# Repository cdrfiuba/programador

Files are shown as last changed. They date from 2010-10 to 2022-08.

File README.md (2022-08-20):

# Programador del Club de Robótica

El club cuenta con varios programadores ISP.

Cada programador cuenta con dos conexiones:
* Target (targ)
    - La conexión más usada. Sirve para programar un microcontrolador externo.
* ISP
    - Sirve para programar el programador (usualmente usando otro programador del club).
      De esta forma un programador sirve para crear más programadores.

## Conexiones

Cada puerto cuenta con 6 pines conectados a un cable plano:

- VCC (usualmente +5V que vienen de la conexión USB)
- GND
- SCK Señal de clock.
- RESET Permite "apagar" el microcontrolador y programarlo por SPI. De esa forma los demás pines pueden ser usados para otras tareas cuando el microcontrolador no está siendo programado.
- MISO (master-in slave-out)<sup>1</sup> Datos del microcontrolador al programador.
- MOSI (master-out slave-in)<sup>1</sup> Datos del programador al microcontrolador.

<sup>1 Nota: SIMO y SOMI suelen ser nombres más simpáticos pero menos usados.</sup>

La ubicación de cada pin en el puerto se muestra a continuación

<p align="center">
    Ubicación de cada pin en el puerto.
</p>

## Pequeña guía para programar un microcontrolador externo

Se utiliza el microcontrolador `ATMEGA168A` a modo de ejemplo (ya que el club cuenta con varios).

La siguiente guía asume el uso de un oscilador externo, si bien el microcontrolador puede ser programador utilizando su oscilador interno.

Se conecta al microcontrolador como muestra la siguiente figura. El valor ideal de los capacitores conectados al cristal se detalla en la hoja de datos del microcontrolador. Para este microcontrolador los capacitores recomendados son de 12pF a 22pF. El capacitor de desacople no es requerido pero es siempre una buena idea agregar uno.

<p align="center">
    Diagrama de la conexión en un protoboard
</p>

Asumiendo que se utiliza un cristal de 16 MHz se crea un archivo `main.c` con el siguiente código:

```C
#include <avr/io.h>
#define F_CPU 16000000UL  // Corresponde a 16 MHz
#include <util/delay.h>

int main (void) {
  DDRC |= _BV(DDC3);  // Se setea el pin 26 como salida

  while(1) {
      PORTC |= _BV(PC3);  // Se prende el pin 26

      _delay_ms(1); // Se espera un milisegundo

      PORTC &= ~_BV(PC3);  // Se apaga el pin 26

      _delay_ms(1);  // Se espera otro milisegundo
  }

  return 1;
}
```

Este código produce una onda cuadrada de 500Hz a la salida del pin 26.

Para programadorlo se crea el siguiente script `programar.sh`

```bash
#!/usr/bin/env sh

# Compilación del programa
avr-gcc -Os -mmcu=atmega168a -c -o main.o main.c
avr-gcc -Os -mmcu=atmega168a -o main.elf main.o
avr-objcopy -O ihex -R .eeprom main.elf main.hex

# Cargar el programa en el microcontrolador
avrdude -v -p m168 -c usbtiny -U flash:w:main.hex

# Limpieza de los archivos generados
rm main.o main.hex main.elf
```

A su vez se crea un script `fusibles.sh` para setear los fuses del microcontrolador
Si bien se puede obtener el valor de los fusibles a mano, existen páginas que ya hacen este trabajo.
Una posible página es https://www.engbedded.com/fusecalc
Esta página además posee la ventaja de darnos los flags para el comando de `avrdude`.

```bash
#!/usr/bin/env bash

avrdude -v -p m168 -c usbtiny -U lfuse:w:0xce:m -U hfuse:w:0xdf:m -U efuse:w:0xf9:m
```

Se da permiso de ejecución a ambos scripts por única vez
```console
$ chmod +x programar.sh
$ chmod +x fusibles.sh
```

Se setean los fusibles por única vez. Puede correrse también en el futuro si, por ejemplo, se desea dividir la cuenta del clock por 8, o utilizar el oscilador interno u otras razones. Pero ha de tenerse en cuenta que se debe modificar el script.

```console
$ ./fusibles.sh
```

Se programa el microcontrolador

```console
$ ./programar.sh
```

Ahora puede corroborarse que a la salida del pin 26 hay una onda cuadrada de 500Hz.

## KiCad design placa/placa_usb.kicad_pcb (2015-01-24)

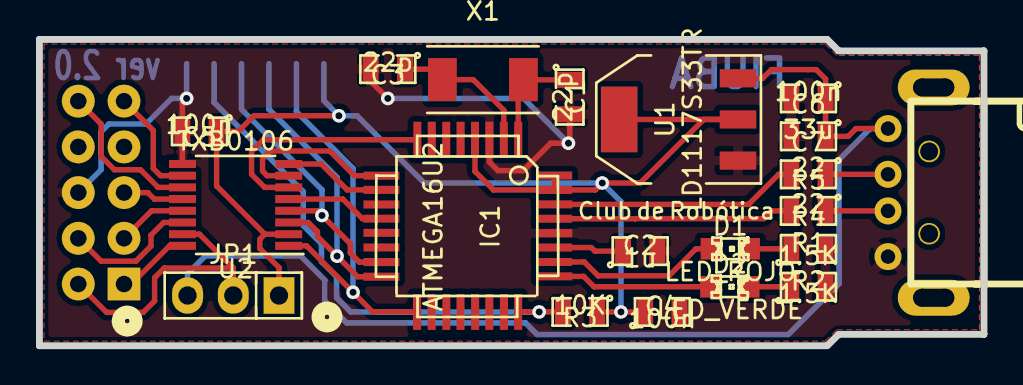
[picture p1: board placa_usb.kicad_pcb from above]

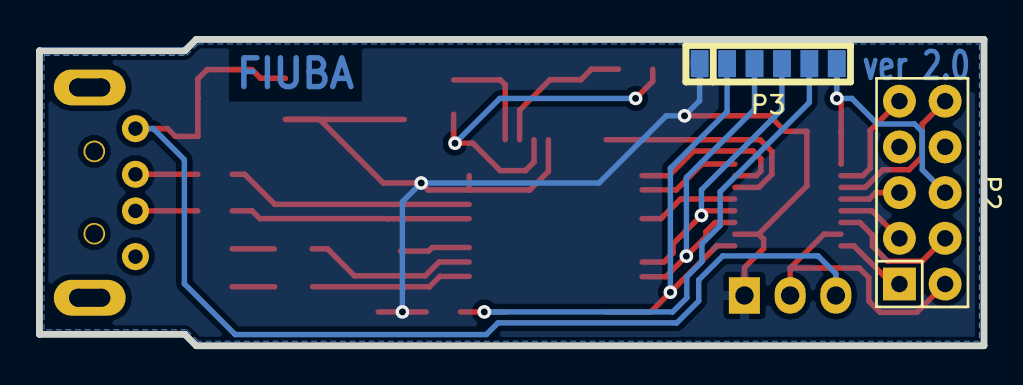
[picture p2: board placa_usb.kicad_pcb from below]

Board: 2 copper layers, 52.5 x 17.0 mm, 22 parts (2 on the bottom side), 29 nets.

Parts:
C1, C3: 22p; SMD-0805
C2: 1u; SMD-0805
C4, C5, C6: 100n; SMD-0805
C7: 33u; SMD-0805
D1: LED_ROJO; LED-0805
D2: LED_VERDE; LED-0805
IC1: ATMEGA16U2; TQFP-32
JP1: JUMPER3; Socket_Strip_Straight_1x03
P1: USB_A; USB_A_custom
P2: CONN_02X05; Socket_Strip_Straight_2x05
P3: CONN_01X06; Socket_Strip_smd_1x06
R1, R2: 1.5K; SMD-0805
R3: 10K; SMD-0805
R4, R5: 22; SMD-0805
U1: LD1117S33TR; SOT-223
U2: TXB0106; TSSOP-16_4.4x5mm_Pitch0.65mm
X1: 8MHz; Crystal_SMD_0603_2Pads_obsolete

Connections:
+3V3: C4.1, C5.1, IC1.4, IC1.31, IC1.32, JP1.1, P3.1, R3.1, U1.2, U2.2
+5V: C6.1, C7.1, JP1.3, P1.1, U1.3
/D+: IC1.29, R4.2
/D-: IC1.30, R5.2
/Enable: IC1.10, U2.8
/MISO: IC1.17, P3.2, U2.1
/MISO-O: P2.1, U2.16
/MOSI: IC1.16, P3.3, U2.3
/MOSI-O: P2.4, U2.14
/RESET: IC1.24, P3.5, R3.2
/RST: IC1.12, U2.5
/RST-O: P2.5, U2.12
/RX: IC1.8, U2.6
/RX-O: P2.10, U2.11
/Rojo: D1.1, IC1.26
/SCK: IC1.15, P3.4, U2.4
/SCK-O: P2.3, U2.13
/TX: IC1.9, U2.7
/TX-O: P2.9, U2.10
/VCC-O: JP1.2, P2.2, U2.15
/Verde: D2.1, IC1.25
GND: C1.2, C2.2, C3.2, C4.2, C5.2, C6.2, C7.2, IC1.3, IC1.28, P1.4, P2.6, P3.6, R1.2, R2.2, U1.1, U2.9
unnamed: C1.1, IC1.1, X1.2
unnamed: C2.1, IC1.27
unnamed: C3.1, IC1.2, X1.1
unnamed: D1.2, R1.1
unnamed: D2.2, R2.1
unnamed: P1.2, R5.1
unnamed: P1.3, R4.1

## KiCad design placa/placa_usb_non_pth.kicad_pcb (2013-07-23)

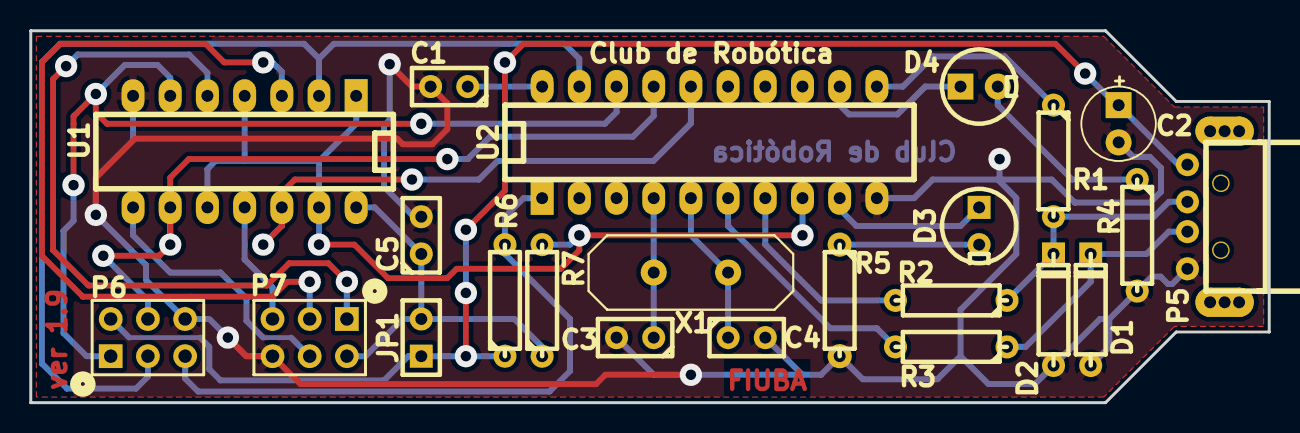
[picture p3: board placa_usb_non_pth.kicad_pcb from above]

Board: 2 copper layers, 84.6 x 25.4 mm, 23 parts (0 on the bottom side), 24 nets.

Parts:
C1, C5: 100n; C1
C2: 100u; C1V5
C3, C4: 22p; C1
D1, D2: 3.6V; D3
D3: LED_VERDE; LEDV
D4: LED_ROJO; LEDV
JP1: VCC; SIL-2
P5: USB_A; USB_A_custom
P6: ISP; pin_array_3x2
P7: Targ.; pin_array_3x2
R1, R4, R5: 1.5K; R3-LARGE_PADS
R2, R3: 27; R3-LARGE_PADS
R6: 10K; R3-LARGE_PADS
R7: 470k; R3-LARGE_PADS
U1: 74HC125N; 14DIP-ELL300
U2: ATTINY2313DIP/SO; DIP-20__300_ELL
X1: 12MHz; HC-18UV

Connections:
+5V: C1.1, C2.1, JP1.1, P5.1, P6.2, R6.1, U2.20
/Enable: R7.2, U1.1, U1.4, U1.10, U1.13, U2.8
/MISO: P6.1, U1.6, U2.18
/MOSI: P6.4, U1.9, U2.17
/PD2: R3.2, U2.6
/PD3: R2.2, U2.7
/PD6: R1.1, U2.11
/RST: P6.5, R6.2, U2.1
/RST_B: U1.12, U2.16
/Rojo: D4.1, U2.12
/SCK: P6.3, U1.2, U2.19
/Verde: D3.1, U2.9
GND: C1.2, C2.2, C3.2, C4.2, C5.2, D1.1, D2.1, P5.4, P6.6, P7.6, R4.2, R5.2, U1.7, U2.10
unnamed: D4.2, R4.1
unnamed: D3.2, R5.1
unnamed: P7.5, U1.11
unnamed: C3.1, U2.4, X1.1
unnamed: C4.1, U2.5, X1.2
unnamed: D1.2, P5.3, R3.1
unnamed: D2.2, P5.2, R1.2, R2.1
unnamed: P7.3, U1.3
unnamed: P7.4, U1.8
unnamed: P7.1, U1.5
VCC: C5.1, JP1.2, P7.2, R7.1, U1.14

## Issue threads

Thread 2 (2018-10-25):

url oficial del proyecto: programador

robertocabellon, 2018-10-25:
En la pagina del proyecto "Programador" en el sitio del labi https://labi.fi.uba.ar/labi/programador creo que el enlace al sitio oficial deberia direccionar a una subpagina de la del club, algo asi como:  clubderobotica.com.ar/programador.

MisaelK, 2022-08-20:
Veo que esto caducó... el sitio de LABi hasta cambió de manos ya.

Closed 2022-08-20.

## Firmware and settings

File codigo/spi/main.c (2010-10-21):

// ======================================================================
// Control a parallel port AVR programmer (avrdude type "bsd") via USB.
//
// Copyright (C) 2006 Dick Streefland
//
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
#include <avr/io.h>
#include "usb.h"

enum
{
	// Generic requests
	USBTINY_ECHO,		// echo test
	USBTINY_READ,		// read byte
	USBTINY_WRITE,		// write byte
	USBTINY_CLR,		// clear bit 
	USBTINY_SET,		// set bit
	// Programming requests
	USBTINY_POWERUP,	// apply power (wValue:SCK-period, wIndex:RESET)
	USBTINY_POWERDOWN,	// remove power from chip
	USBTINY_SPI,		// issue SPI command (wValue:c1c0, wIndex:c3c2)
	USBTINY_POLL_BYTES,	// set poll bytes for write (wValue:p1p2)
	USBTINY_FLASH_READ,	// read flash (wIndex:address)
	USBTINY_FLASH_WRITE,	// write flash (wIndex:address, wValue:timeout)
	USBTINY_EEPROM_READ,	// read eeprom (wIndex:address)
	USBTINY_EEPROM_WRITE,	// write eeprom (wIndex:address, wValue:timeout)
	USBTINY_DDRWRITE,        // set port direction
	USBTINY_SPI1,            // a single SPI command
	USBTINY_CONFIGURE	 // if command sent, use the inverted sck for 8253. (wValue = status, wIndex = comando)
};

// ----------------------------------------------------------------------
// Programmer output pins:
//	LED	PB0	(D0)
#define LED PB0
//	VCC	PB1	(D1)
//	VCC	PB2	(D2)
//	VCC	PB3	(D3)
//	RESET	PB5	(D4)
#define RESET PB4
//	MOSI	PB5	(D5)
#define MOSI  PB5
//	SCK	PB7	(D7)
#define SCK   PB7

// ----------------------------------------------------------------------
#define	PORT		PORTB
#define	DDR		DDRB
#define	POWER_MASK	_BV(LED)
#define	RESET_MASK	_BV(RESET)
#define	SCK_MASK	_BV(SCK)
#define	MOSI_MASK	_BV(MOSI)
#define LED_MASK        _BV(LED)

// ----------------------------------------------------------------------
// Programmer input pins:
//	MISO	PB6
#define MISO       6
// ----------------------------------------------------------------------
#define	PIN		PINB
#define	MISO_MASK	_BV(MISO)

// ----------------------------------------------------------------------
// Local data
// ----------------------------------------------------------------------
static	byte_t		sck_period;	// SCK period in microseconds (1..250)
static	byte_t		poll1;		// first poll byte for write
static	byte_t		poll2;		// second poll byte for write
static	uint_t		address;	// read/write address
static	uint_t		timeout;	// write timeout in usec
static	byte_t		cmd0;		// current read/write command byte
static	byte_t		cmd[4];		// SPI command buffer
static	byte_t		res[4];		// SPI result buffer
static	byte_t		status;		


//ximmmTTT

#define TAMANIO_MASK		0x07
#define TAMANIO_AVR		0x04
#define TAMANIO_8253		0x04
#define TAMANIO_8252		0x03

#define MICRO_S51_MASK		0x38
#define MICRO_AVR		0x00
#define MICRO_8253		0x08
#define	MICRO_8252		0x10

#define INVERTED_SCK_MASK	0x40	
#define AVR_SCK			0x00

// ----------------------------------------------------------------------
// Delay exactly <sck_period> times 0.5 microseconds (6 cycles).
// ----------------------------------------------------------------------
__attribute__((always_inline))
static	void	delay ( void )
{
	asm volatile(
		"	mov	__tmp_reg__,%0	\n"
		"0:	rjmp	1f		\n"
		"1:	nop			\n"
		"	dec	__tmp_reg__	\n"
		"	brne	0b		\n"
		: : "r" (sck_period) );
}

// ----------------------------------------------------------------------
// Issue one SPI command.
// ----------------------------------------------------------------------
//__attribute__((naked))
static	void	spi ( byte_t* cmd, byte_t* res, int i )
{
	byte_t	c;
	byte_t	r;
	byte_t	mask;

	while (i != 0)
	{
	  i--;
		c = *cmd++;
		r = 0;
		for	( mask = 0x80; mask; mask >>= 1 )
		{
			if	( c & mask )
			{
				PORT |= MOSI_MASK;
			}
//			if (! status & INVERTED_SCK_MASK )
				delay();

			PORT |= SCK_MASK;
			delay();
			r <<= 1;
			if	( PIN & MISO_MASK )
			{
				r++;
			}
			PORT &= ~ SCK_MASK;
//			if ( status & INVERTED_SCK_MASK )
//				delay();
			
			PORT &= ~ MOSI_MASK;
		}
		*res++ = r;
	}
}

// ----------------------------------------------------------------------
// Create and issue a read or write SPI command.
// ----------------------------------------------------------------------
static	void	spi_rw ( void )
{
	unsigned char offset = 0;
	uint_t	a;
	uint_t	tam = (status & TAMANIO_MASK);	

	a = address++;
	cmd[0] = cmd0;
	if ( ( !(status & MICRO_S51_MASK) ) &&  ( ! (cmd0 & 0x80) ) )
	{	//Es AVR 							// NOT eeprom
		if ( a & 1 )
		{
			cmd[0] |= 0x08;	//La H
		}
		a >>= 1;	//Corro la direccion
	} 
	cmd[1] = a >> 8;
	cmd[2] = a;
	
	if ( (status & MICRO_S51_MASK ) == MICRO_8252 )
	{
		cmd[1] <<= 3;
		cmd[1] |= cmd0;
		offset = 1;
	}
	spi( cmd + offset, res, tam );
}

// ----------------------------------------------------------------------
// Handle a non-standard SETUP packet.
// ----------------------------------------------------------------------
extern	byte_t	usb_setup ( byte_t data[8] )
{
	byte_t	mask;
	byte_t	req;
	byte_t	ans = 0;
	byte_t	cmd0_temp;

	// Generic requests
	req = data[1];

	// Programming requests
	if	( req == USBTINY_POWERUP )
	{
		sck_period = data[2];
		mask = POWER_MASK;
		if	( data[4] )
		{
			mask |= RESET_MASK;
		}
		// Use AVR por default
		status = AVR_SCK | MICRO_AVR | TAMANIO_AVR;
		
		PORTD &= ~_BV(4);
		DDR  = POWER_MASK | RESET_MASK | SCK_MASK | MOSI_MASK;
		PORT = mask;
		// return 0;
	}
	else if	( req == USBTINY_POWERDOWN )
	{
	  //PORT |= RESET_MASK;
		DDR  = 0x00;
		PORT = 0x00;
		PORTD |= _BV(4);
		// return 0;
	}
	else if ( req == USBTINY_CONFIGURE )
	{
		status = data[2];
		cmd0 = data[4];
	}
	/*else if	( ! PORT )
	{
		//return 0;
	}*/
	else if	( req == USBTINY_SPI )
	{
	  spi( data + 2, data + 0, 4 );
		ans = 4;
		//return 4;
	}
	else if	( req == USBTINY_SPI1 )
	{
	  spi( data + 2, data + 0, 1 );
		ans = 1;
		//return 1;
	}
	else if	( req == USBTINY_POLL_BYTES )
	{
		poll1 = data[2];
		poll2 = data[3];
		//return 0;
	}
	else 
	{
		address = * (uint_t*) & data[4];
		if	( req == USBTINY_FLASH_READ )
		{
			cmd0_temp = 0x20;
			ans = 0xff;
			//return 0xff;	// usb_in() will be called to get the data
		}
		else if	( req == USBTINY_EEPROM_READ )
		{
			cmd0_temp = 0xa0;
			ans =  0xff;
			//return 0xff;	// usb_in() will be called to get the data
		}
		else {
			timeout = * (uint_t*) & data[2];
			if	( req == USBTINY_FLASH_WRITE )
			{
				cmd0_temp = 0x40;
				//return 0;	// data will be received by usb_out()
			}
			else if	( req == USBTINY_EEPROM_WRITE )
			{
				cmd0_temp = 0xc0;
				//return 0;	// data will be received by usb_out()
			}
		}	
		if ( ! (status & MICRO_S51_MASK) )		//Solo grabo el dato temp en cmd0 si estoy grabando un AVR	
		{						//Si estoy programando un S51, tengo que pasarlo en la trama CONFIGURE
			cmd0 = cmd0_temp;
		}
	}
	return ans;
}

// ----------------------------------------------------------------------
// Handle an IN packet.
// ----------------------------------------------------------------------
extern	byte_t	usb_in ( byte_t* data, byte_t len )
{
	byte_t	i;

	for	( i = 0; i < len; i++ )
	{
		spi_rw();
		data[i] = res[3];
	}
	return len;
}

// ----------------------------------------------------------------------
// Handle an OUT packet.
// ----------------------------------------------------------------------
extern	void	usb_out ( byte_t* data, byte_t len )
{
	byte_t	i;
	uint_t	usec;
	byte_t	r;

	for	( i = 0; i < len; i++ )
	{
		cmd[3] = data[i];
		spi_rw();
		cmd[0] ^= 0x60;	// turn write into read
		for	( usec = 0; usec < timeout; usec += 32 * sck_period )
		{	// when timeout > 0, poll until byte is written
		  spi( cmd, res, 4 );
			r = res[3];
			if	( r == cmd[3] && r != poll1 && r != poll2 )
			{
				break;
			}
		}
	}
}	 
	 

// ----------------------------------------------------------------------
// Main
// ----------------------------------------------------------------------
__attribute__((naked))		// suppress redundant SP initialization
extern	int	main ( void )
{
  PORTD |= _BV(4);
  DDRD = _BV(6) | _BV(5) | _BV(4); // setup USB pullup, LED pin and buffer select pins to output
  usb_init();
  PORTD = _BV(6) | _BV(4); // pull pull-up and buffer disable high

  for	( ;; )
    {
      usb_poll();
    }
  return 0;
}

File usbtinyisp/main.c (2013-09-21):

// ======================================================================
// USB AVR programmer and SPI interface
//
// http://www.ladyada.net/make/usbtinyisp/
//
// This code works for both v1.0 and v2.0 devices.
//
// Copyright 2006-2010 Dick Streefland
//
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
#include <avr/io.h>
#include "defines.h"
#include "macros.h"
#include "def.h"
#include "usb.h"
#include "messages.h"
#include "avr_spi.h"
#include "s8253.h"



//Pointers
static void (*pUsb_out)(byte_t* data, byte_t len);
static byte_t (*pUsb_in)(byte_t* data, byte_t len);
static byte_t (*pUsb_setup)(byte_t* data);

void ConfigurePointersDefaultValue()
{
		pUsb_in  = &AVR_usb_in;
		pUsb_out = &AVR_usb_out;
		pUsb_setup = &AVR_usb_setup;
}

void DefinePointers(uint16_t protocol)
{
	if (protocol == PROTOCOL_SPI_S8253)
	{
		pUsb_in  = &s8253_usb_in;
		pUsb_out = &s8253_usb_out;
		pUsb_setup = &s8253_usb_setup;
	}
	else
	{
		ConfigurePointersDefaultValue();
	}	
}

// ----------------------------------------------------------------------
// Handle a non-standard SETUP packet.
// ----------------------------------------------------------------------
extern	byte_t	usb_setup ( byte_t data[8] )
{
	byte_t	mask;
	byte_t	req;
	byte_t	ans = 0;

	/*tGenericMessage * genericRequest;
	genericRequest = data;	
	req = genericRequest->typeRequest;*/
	
	// Generic requests
	req = data[1];

	// Programming requests
	if	( req == USBTINY_POWERUP )
	{
		sck_period = data[2];
		mask = POWER_MASK;
		if	( data[4] )
		{
			mask |= RESET_MASK;
		}
		// Use AVR por default
		//status = AVR_SCK | MICRO_AVR | TAMANIO_AVR;
				
		BUFFER_ON;
		DDR  = POWER_MASK | RESET_MASK | SCK_MASK | MOSI_MASK;		
		PORT = mask;
		
		ConfigurePointersDefaultValue();
		//return 0;
	}
	else if	( req == USBTINY_POWERDOWN )
	{
		DDR  = 0x00;
		PORT = 0x00;
		BUFFER_OFF;
		// return 0;
	}
	else if (req == USBTINY_PROTOCOL) 
	{
		DefinePointers(data[2]);
	} 
	else 
	{
		ans = (*pUsb_setup)(data);
	}
	
	return ans;		
}



// ----------------------------------------------------------------------
// Handle an IN packet.
// ----------------------------------------------------------------------
extern	byte_t	usb_in ( byte_t* data, byte_t len )
{   
	return (*pUsb_in)(data, len);  
}

// ----------------------------------------------------------------------
// Handle an OUT packet.
// ----------------------------------------------------------------------
extern	void	usb_out ( byte_t* data, byte_t len )
{
	(*pUsb_out)(data, len);
}


// ----------------------------------------------------------------------
// Main
// ----------------------------------------------------------------------
__attribute__((naked))		// suppress redundant SP initialization
extern	int	main ( void )
{
  
  DDRD = _BV(6) | _BV(5) | _BV(4); // setup USB pullup, LED pin and buffer select pins to output
  
  
  BUFFER_ON;
  BUFFER_AS_OUTPUT;
  //LCD_AS_OUTPUT;
  //USB_AS_OUTPUT;
  usb_init();
  
  PORTD = _BV(6) | _BV(4); // pull pull-up and buffer disable high

  for	( ;; )
    {
      usb_poll();
    }
  return 0;
}

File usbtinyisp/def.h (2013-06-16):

// ======================================================================
// Common definitions for the USB driver
//
// Copyright 2006-2010 Dick Streefland
//
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
#ifdef __ASSEMBLER__
#define	__SFR_OFFSET		0
#endif
#include <avr/io.h>
#include "usbtiny.h"

// Preprocessor magic
#define	CAT2(a,b)		CAT2EXP(a, b)
#define	CAT2EXP(a,b)		a ## b
#define	CAT3(a,b,c)		CAT3EXP(a, b, c)
#define	CAT3EXP(a,b,c)		a ## b ## c

// I/O Ports for USB
#define	USB_IN			CAT2(PIN, USBTINY_PORT)
#define	USB_OUT			CAT2(PORT, USBTINY_PORT)
#define	USB_DDR			CAT2(DDR, USBTINY_PORT)

// I/O bit masks for USB
#define	USB_MASK_DMINUS		(1 << (USBTINY_DMINUS))
#define	USB_MASK_DPLUS		(1 << (USBTINY_DPLUS))
#define	USB_MASK		(USB_MASK_DMINUS | USB_MASK_DPLUS)

// Interrupt configuration
#if	defined	EICRA
#  define USB_INT_CONFIG	EICRA
#else
#  define USB_INT_CONFIG	MCUCR
#endif
#define	USB_INT_CONFIG_SET	((1 << CAT3(ISC,USBTINY_INT,1)) | (1 << CAT3(ISC,USBTINY_INT,0)))
#if	defined SIG_INT0
#  define USB_INT_VECTOR	CAT2(SIG_INT, USBTINY_INT)
#else
//#  define USB_INT_VECTOR	CAT2(SIG_INTERRUPT, USBTINY_INT)
#define USB_INT_VECTOR CAT3(INT, USBTINY_INT, _vect)
#endif

// Interrupt enable
#if	defined	GIMSK
#  define USB_INT_ENABLE	GIMSK
#elif	defined	EIMSK
#  define USB_INT_ENABLE	EIMSK
#else
#  define USB_INT_ENABLE	GICR
#endif
#define	USB_INT_ENABLE_BIT	CAT2(INT,USBTINY_INT)

// Interrupt pending bit
#if	defined	EIFR
#  define USB_INT_PENDING	EIFR
#else
#  define USB_INT_PENDING	GIFR
#endif
#define	USB_INT_PENDING_BIT	CAT2(INTF,USBTINY_INT)
#if	defined INF0 && ! defined INTF0
#  define	INTF0		INF0	// fix for incorrect definition in iotn13.h
#endif

// USB PID values
#define	USB_PID_SETUP		0x2d
#define	USB_PID_OUT		0xe1
#define	USB_PID_IN		0x69
#define	USB_PID_DATA0		0xc3
#define	USB_PID_DATA1		0x4b
#define	USB_PID_ACK		0xd2
#define	USB_PID_NAK		0x5a
#define	USB_PID_STALL		0x1e

// Various constants
#define	USB_BUFSIZE		11	// PID + data + CRC

// Bit manipulation macros
#define	BIT_CLR(reg,bit)	{ (reg) &= ~ _BV(bit); }
#define	BIT_SET(reg,bit)	{ (reg) |=   _BV(bit); }
#define	BIT_TST(reg,bit)	(((reg) & _BV(bit)) != 0)

// I/O port manipulation macros
#define	DDR_CLR(p,b)		BIT_CLR(DDR  ## p, b)
#define	DDR_SET(p,b)		BIT_SET(DDR  ## p, b)
#define	PORT_CLR(p,b)		BIT_CLR(PORT ## p, b)
#define	PORT_SET(p,b)		BIT_SET(PORT ## p, b)
#define	PORT_TST(p,b)		BIT_TST(PORT ## p, b)
#define	PIN_TST(p,b)		BIT_TST(PIN  ## p, b)
#define	PIN_SET(p,b)		BIT_SET(PIN  ## p, b)

// Macros that can be used with an argument of the form (port,bit)
#define	INPUT(bit)		DDR_CLR bit
#define	OUTPUT(bit)		DDR_SET bit
#define	CLR(bit)		PORT_CLR bit
#define	SET(bit)		PORT_SET bit
#define	ISSET(bit)		PORT_TST bit
#define	TST(bit)		PIN_TST bit
#define	TOGGLE(bit)		PIN_SET bit

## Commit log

2008-07-09 Initial import
    [ir.sch]
2008-07-09 Cambiamos usb_setup para que sean elseif 2014 bytes.
2008-07-09 Cambio el if por un case en usb_setup
2008-07-09 Agregamos la opcion para invertir el sck. Sacamos el port y el echo.
2008-07-09 Borro el main.hex del darcs
2008-07-11 Lectura en rafaga intento 1
    Ahora puede recibir en rafaga las lecturas y escrituras,. No esta
    probado. Tuve que comentar el invertir SCK para que entre.
2008-07-11 Intente agregar modo rafaga 8051 El AVR anda como antes, pero el modo rafaga no anda con el 8253. hace cualquier cosa. Sin ideas por ahora.
2008-07-14 funciona modo rafaga con el 8253
2008-07-15 Funciona el tamanio como argumento de spi_rw. COMENTE una de las funciones de USB para ganar espacio.
2008-07-19 Agrego esqueleto de documentacion en latex.
2008-07-19 Agregue lo que habia escrito en texto plano. se ve FEO, no se latex. BU :(
2008-09-29 Agrego ultimo PCB, falta el nuevo conector USB.
    [placa_usb.brd]
2008-10-23 Borro el archivo conector_usb.mod
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2009-03-21 Sacamos el plano de tierra y escribimos FIUBA en el pcb.
    [placa_usb.brd]
2009-04-14 Arreglo el texto que pego gabriel en el tex.
2010-08-31 Creo un directorio para la placa, para que quede mas ordenado.
    [placa_usb.brd, placa_usb.sch]
2010-09-12 Saco el jumper de alimentacion del buffer que no servia para nada.
    [placa_usb.brd, placa_usb.sch]
2010-09-14 Modifico el esquematio: * Saco el jumper de Puerto a Vcc (el de Vcc a buffer ya lo habia sacado) * Cambio los conectores de 5x2 por los de 3x2 * Agrego una R de pull up de 470K en el enable del buffe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
    [placa_usb.sch]
2010-09-14 Actualizo la asignacion de componentes por los ultimos cambios en el esquematico.
2010-10-16 Correccion en el esquematico, y placa doble faz. Falta texto en la placa
    [placa_usb.brd, placa_usb.sch]
2010-10-16 Arregle un par de pistas, la serigrafia, y agregue texto del club
    [placa_usb.brd]
2010-10-16 Cambio los textos de los conectores y el jumper.
    [placa_usb.brd]
2010-10-16 Vuelvo a cambiar los textos y pongo un punto marcando el 1 de los conectores.
    [placa_usb.brd]
2010-10-16 Agrego titulo, version, autor y licencia a las propiedades de la hoja del pcb.
    [placa_usb.brd]
2010-10-19 Pase el texto a la capa de serigrafia y agrande los 'puntos' en los conectores 3x2
    [placa_usb.brd]
2010-10-20 Agregue el numero de version 1.5
    [placa_usb.brd]
2010-10-20 Peque?os cambios a la capa de serigrafia. Movi un par de cartelitos.
    [placa_usb.brd]
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2010-10-21 Version 1.6. Agregamos capacitor de alimentacion y se adecuo el impreso a las especificaciones de Mayer
    [ir.sch, placa_usb.brd, placa_usb.sch]
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2010-10-27 Cambio la licencia en el esquematico porque estaba mal.
    [placa_usb.sch]
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2010-11-28 modifique el esquematico para hacer mas claro el conector usb. cree el componente con las etiquetas correctas
    [placa_usb.sch]
2010-11-28 Arregle el problema del usb invertido en el board. Version 1.7
    [placa_usb.brd, placa_usb.sch]
2010-11-28 Correcciones finales a la version 1.7. Se agrega el archivo .lst que tiene la lista de materiales
    [placa_usb.brd, placa_usb.sch]
2010-12-02 Elimine una conexion innecesaria de Vcc.
    [placa_usb.brd]
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2010-12-06 Actualizacion de las bibliotecas de componentes USB
    [placa_usb.brd, placa_usb.sch]
2010-12-06 Archivos de las bibliotecas, que no parecen utilies pero el kicad se queja si faltan
2010-12-06 Adaptador para Conector miniUSB para corregir el error del PCB_ver_1.6
    [adaptador_miniusb.brd, adaptador_miniusb.sch]
2010-12-09 - Agregue las hojas de datos - Junte todo en una carpeta para trabajar con el avrstudio - Cree un archivo para trabajar solo con el 8253
2011-04-30 Muevo las pistas que pasan por entre medio de los conectores de 2x3 y agrando los pads de los mismos.
    [placa_usb.brd]
2011-05-02 agrande 2 agujeros mas
    [placa_usb.brd]
2011-05-02 Gerber generados
    [placa_usb.brd]
2011-05-17 Creo un nuevo branch con el c?digo actualizado del programador. Cambio nombre del directorio de codigo a usbtinyisp porque me parecio m?s apropiado.
    [ir.sch]
2011-09-17 Se empiezan a implementar los punteros a funciones. La idea es segun el protocolo a usar se apunte el puntero a la funcion correspondiente.
    Hay que tratar de usar los punteros lo menos posible ya que consumen mucho
    espacio en memoria.
2011-10-14 Agrego el proyecto para AVRStudio 5.0 y creo otro set de archivos sobre los que trabajar
2013-06-15 Muevo todo para convertir esta version en la unica
2013-06-16 Terminado para 8253, aunque no funciona (algunas cosas del main estan hardcodeadas). Si pongo para compilar para 4313 en lugar de 2313, no funciona. No pone el vector de interrupciones en el lugar co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
    [macros.h, main.c]
2013-06-16 Vuelve a funcionar como antes (mal) pero ahora bien configurado el 4313. Un problema con la definicion del vector de interrupcion.
    [def.h, main.c]
2013-06-17 Funciono el grabado del programa largo! Todavia esta hardcodeado la elecci?n del s8253.
2013-06-18 Agrego el proyecto de avrstudio 6 para que sea mas facil abrir el proyecto mas adelante
2013-06-18 Version con los dos protocolos. Funciona!! Se agrega el nuevo main.hex
2013-06-18 Agrego las hojas de datos para rapida referencia.
2013-06-19 Agrego un define con la version(no se usa para nada)
2013-07-23 elimino las R a la salida del buffer y conecto la alimentacion del buffer a la salida por el target
    [placa_usb.brd, placa_usb.sch]
2013-07-23 agrego una version para hacer sin PTH, faltaria revisar la serigrafia
    [placa_usb_non_pth.kicad_pcb]
2013-07-23 arregle la serigrafia y corregi algunos detalles, mande a fabricar una
    [placa_usb_non_pth.kicad_pcb]
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2013-08-09 Se corrige celigrafia LED, se agrega signo +.
    Versi?n enviada a fabricar.
    [placa_usb.brd]
2013-09-21 Arreglo la compilacion en Linux.
    El Makefile tenia mezclada la capitalizacion del archivo avr_spi.c/h
    [main.c]
2015-01-24 Plantilla con 4 placas de programador v1.8
    [placa_usb_plantilla.kicad_pcb]
2015-01-24 Version de prueba de la placa 2.0 con micro smd
    [placa_usb.brd, placa_usb.kicad_pcb, placa_usb.sch]
2024-07-06 Agregar links a la Wiki para gente no acostumbrada a GitHub. Agregar documentación relacionada a quemar bootloader de Arduino

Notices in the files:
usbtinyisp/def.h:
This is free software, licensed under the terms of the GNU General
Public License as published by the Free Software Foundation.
